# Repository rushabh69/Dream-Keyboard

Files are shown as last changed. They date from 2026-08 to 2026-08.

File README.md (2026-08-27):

# My KEEB Keyboard

A 65% mechanical keyboard I'm building for [Hack Club KEEB](https://keeb.hackclub.com/), with
a rotary encoder, hotswap switches, RGB, and an OLED.

## Specs

- 65% layout with an encoder cluster (67 keys, 5×15 matrix)
- Rotary encoder (volume / page scroll), hotswap switches
- RGB lighting (SK6812) and a 128×64 OLED
- Raspberry Pi Pico (RP2040)
- RMK firmware (Rust)
- PCB designed in KiCad
- 3D-printed case, designed in Onshape

## Build

The PCB is in [`pcb/`](pcb/) (KiCad), the case in [`case/`](case/) (Onshape), and the
firmware config in [`firmware/keyboard.toml`](firmware/keyboard.toml). I'm keeping the
build log in [`JOURNAL.md`](JOURNAL.md) as I go.

## Files

- [`pcb/`](pcb/) — PCB and schematic files (KiCad), plus exported Gerbers and drill files
- [`case/`](case/) — case and plate CAD, exported as STEP/STL (mm)
- [`firmware/`](firmware/) — RMK firmware config
- [`photos/`](photos/) — build photos
- [`bom.csv`](bom.csv) — parts list
- [`JOURNAL.md`](JOURNAL.md) — build log

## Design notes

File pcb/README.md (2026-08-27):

# PCB

KiCad project for the keyboard PCB. 65% layout with an encoder cluster, hotswap sockets,
RGB and an OLED. Raspberry Pi Pico as the controller, one 1N4148 diode per key.

Matrix: 5 rows × 15 cols. Pin mapping (matches `firmware/keyboard.toml`):

| Signal | Pico GPIO |
|---|---|
| ROW0–ROW4 | GP0–GP4 |
| COL0–COL14 | GP5–GP19 |
| Encoder A / B | GP20 / GP21 |
| RGB (WS2812 DIN) | GP22 |
| OLED SDA / SCL (I2C1) | GP26 / GP27 |

Parts / footprints to add (marbastlib for the keyboard parts):

- **Hotswap sockets** — Kailh MX hotswap footprint (marbastlib `SW_MX_1u` hotswap variant),
  not soldered switches.
- **Encoder** — EC11 rotary encoder footprint; A/B to GP20/GP21, encoder push wired into the
  matrix at (row0, col14).
- **RGB** — SK6812 MINI-E LEDs chained (DIN→DOUT), data from GP22, plus decoupling caps.
- **OLED** — 4-pin I2C header (GND/VCC/SCL/SDA) to GP27/GP26.

Switches on the 19.05 mm grid. Run DRC, then export Gerbers + drill files to `gerbers/`.

## Start from the layout (auto-place the matrix)

`layout.kle.json` is the full 65% layout with each key labelled by its `row,col` matrix
position. Instead of placing 67 keys by hand:

`dream-keyboard.net` is a pre-generated KiCad netlist for the whole matrix — all 67
switches + 67 diodes, wired to nets ROW0–ROW4 and COL0–COL14. It was generated from
`layout.kle.json` with `kle2netlist` (switch = `PCM_marbastlib-mx:SW_MX_1u`,
diode = `Diode_THT:D_DO-35_SOD27_P7.62mm_Horizontal`).

Bring the matrix into a PCB:

1. Install the **marbastlib** library so the switch footprint resolves.
2. New KiCad project in this folder → open the **PCB Editor**.
3. **File → Import → Netlist** → pick `dream-keyboard.net` → **Update PCB**. All 67
   switch+diode pairs load with the matrix already connected (you'll see the ratsnest).
4. Install the **kbplacer** plugin (Plugin and Content Manager) and run it with
   `layout.kle.json` to auto-arrange the switches on the 19.05 mm grid.
   - kbplacer: https://github.com/adamws/kbplacer
5. Hand-add the Pico, encoder, OLED header, and SK6812 chain, and wire them to the GPIO in
   the pin table above.
6. Draw the outline, route, DRC, export Gerbers.

The netlist covers only the key matrix — the Pico/encoder/OLED/RGB are added by hand.

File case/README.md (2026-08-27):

# Case

Case and plate designed in Onshape, 3D printed.

Rough dimensions: base 3–5 mm, walls ~12 mm, 14 mm switch cutouts on the 19.05 mm grid,
USB slot for the Pico's USB-C. Also needs a cutout/window for the OLED and clearance for
the encoder knob in the top-right. Exported to STL (mm) for printing and STEP for the repo.

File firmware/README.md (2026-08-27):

# Firmware

RMK (Rust) firmware for the Pico. Config is in [`keyboard.toml`](keyboard.toml).

Features wired in:
- **Rotary encoder** — volume on the base layer, page scroll on Fn.
- **OLED (SSD1306, 128×64, I2C1)** — configured in TOML.
- **Macro cluster** — M1/M2/M3 = copy / paste / cut.
- **Two layers** — base 65% and an Fn layer (F-keys + nav).
- **RGB (WS2812)** — the data line is on GP22, but addressable RGB isn't set up in
  `keyboard.toml`; RMK needs a small amount of Rust for it. Add it after the base build
  works: https://rmk.rs/docs/

## Build & flash

```bash
cargo install rmkit
rmkit init            # rp2040, keyboard.toml
# drop this keyboard.toml over the generated one
cargo build --release
```

Then hold BOOTSEL on the Pico, plug in USB, and copy the `.uf2` to the `RPI-RP2` drive.

The matrix, encoder, and I2C pins in `keyboard.toml` must match the KiCad schematic nets.
Default wiring is col2row (diode cathode → row); add `row2col = true` if it's reversed.

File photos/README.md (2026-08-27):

# Photos

Build and assembly photos, referenced from the journal and main README.

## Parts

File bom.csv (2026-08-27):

ref | component | description | quantity | value | source
SW1-SW67 | Switches | MX mechanical switches | 67 |  | grant
D1-D67 | Diode | 1N4148 (SOD-27 through-hole) | 67 | 1N4148
U1 | Controller | Raspberry Pi Pico | 1 | RP2040
ENC1 | Rotary encoder | Alps EC11 encoder + knob (with push) | 1 | EC11
D101-D105 | RGB | SK6812MINI-E addressable LED (5 zones) | 5 | SK6812
C101-C105 | Capacitor | 100nF decoupling (0805) | 5 | 100nF
J1 | Display | OLED header 1x04 (SSD1306 128x64 module) | 1 | SSD1306
R1-R2 | Resistor | I2C pull-up 4.7k (0805) | 2 | 4.7k
- | Keycaps | MX keycap set | 1 |  | grant
- | Cable | USB-C cable | 1 |  | grant
- | Stabilizers | MX plate/PCB stabilizers | 5
- | Case | 3D-printed case | 1
- | Plate | Switch plate | 1

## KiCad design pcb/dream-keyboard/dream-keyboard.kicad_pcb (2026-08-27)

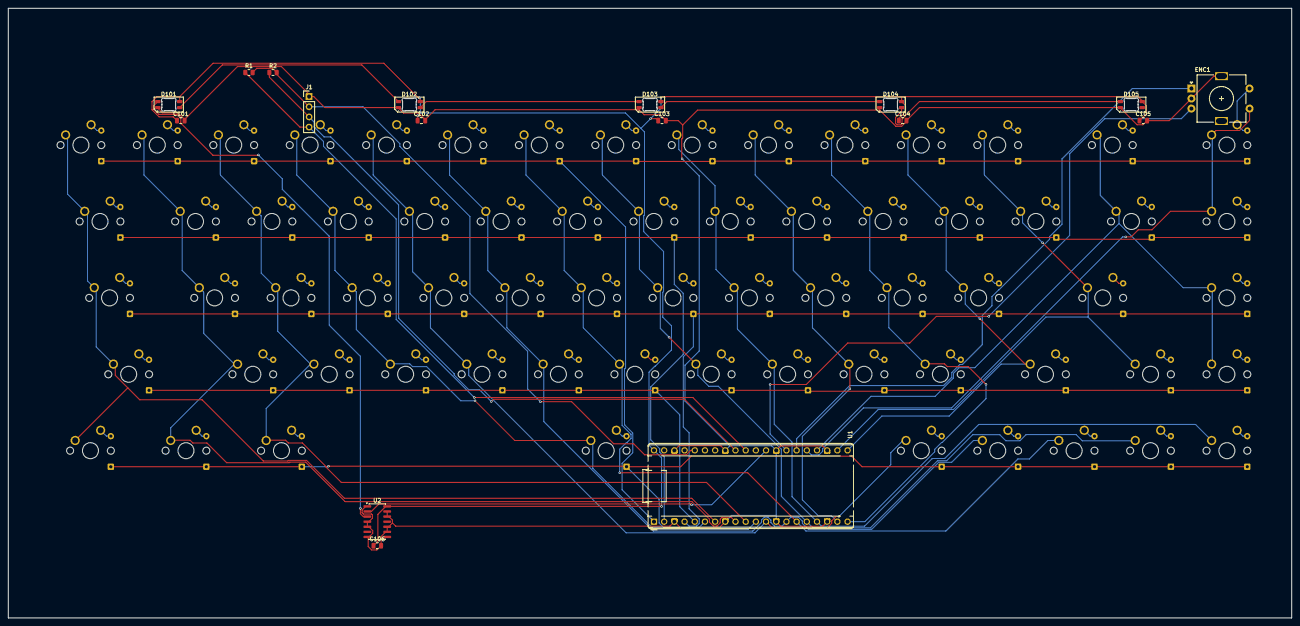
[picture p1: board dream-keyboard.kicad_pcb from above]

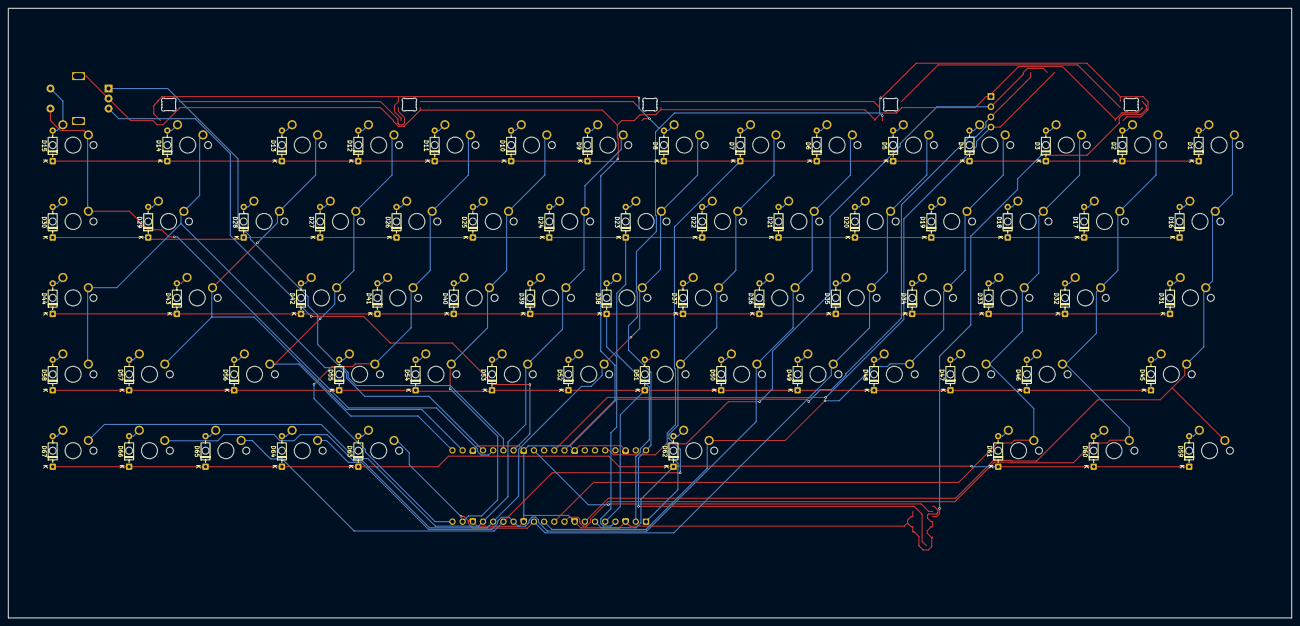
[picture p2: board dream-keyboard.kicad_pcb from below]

Board: 2 copper layers, 320.0 x 152.0 mm, 151 parts (67 on the bottom side), 100 nets.

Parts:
C101, C102, C103, C104, C105, C106: C_0805_2012Metric
D1, D2, D3, D4, D5, D6, D7, D8, D9, D10, D11, D12, D13, D14, D15, D16, D17, D18, D19, D20, D21, D22, D23, D24, D25, D26, D27, D28, D29, D30, D31, D32, D33, D34, D35, D36, D37, D38, D39, D40, D41, D42, D43, D44, D45, D46, D47, D48, D49, D50, D51, D52, D53, D54, D55, D56, D57, D58, D59, D60, D61, D62, D63, D64, D65, D66, D67: D; D_DO-35_SOD27_P7.62mm_Horizontal
D101, D102, D103, D104, D105: LED_SK6812MINI-E_3.2x2.8mm_P1.5mm_ReverseMount
ENC1: RotaryEncoder_Alps_EC11E-Switch_Vertical_H20mm
J1: PinHeader_1x04_P2.54mm_Vertical
R1, R2: R_0805_2012Metric
SW1, SW2, SW3, SW4, SW5, SW6, SW7, SW8, SW9, SW10, SW11, SW12, SW13, SW14, SW15, SW16, SW17, SW18, SW19, SW20, SW21, SW22, SW23, SW24, SW25, SW26, SW27, SW28, SW29, SW30, SW31, SW32, SW33, SW34, SW35, SW36, SW37, SW38, SW39, SW40, SW41, SW42, SW43, SW44, SW45, SW46, SW47, SW48, SW49, SW50, SW51, SW52, SW53, SW54, SW55, SW56, SW57, SW58, SW59, SW60, SW61, SW62, SW63, SW64, SW65, SW66, SW67: SW_Push; SW_MX_1u
U1: RaspberryPi_Pico_Common_THT
U2: SOIC-14_3.9x8.7mm_P1.27mm

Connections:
+3V3: J1.2, R1.2, R2.2, U1.36
+5V: C101.1, C102.1, C103.1, C104.1, C105.1, C106.1, D101.3, D102.3, D103.3, D104.3, D105.3, U1.40, U2.14
COL0: SW1.1, SW16.1, SW31.1, SW45.1, SW59.1, U1.7
COL1: SW2.1, SW17.1, SW32.1, SW46.1, SW60.1, U1.9
COL2: SW3.1, SW18.1, SW33.1, SW47.1, SW61.1, U1.10
COL3: SW4.1, SW19.1, SW34.1, SW48.1, SW62.1, U1.11
COL4: SW5.1, SW20.1, SW35.1, SW49.1, SW63.1, U1.12
COL5: SW6.1, SW21.1, SW36.1, SW50.1, SW64.1, U1.14
COL6: SW7.1, SW22.1, SW37.1, SW51.1, SW65.1, U1.15
COL7: SW8.1, SW23.1, SW38.1, SW52.1, SW66.1, U1.16
COL8: SW9.1, SW24.1, SW39.1, SW53.1, SW67.1, U1.17
COL9: SW10.1, SW25.1, SW40.1, SW54.1, U1.19
COL10: SW11.1, SW26.1, SW41.1, SW55.1, U1.20
COL11: SW12.1, SW27.1, SW42.1, SW56.1, U1.21
COL12: SW13.1, SW28.1, SW43.1, SW57.1, U1.22
COL13: SW14.1, SW29.1, SW44.1, SW58.1, U1.24
COL14: ENC1.S1, SW15.1, SW30.1, U1.25
ENC_A: ENC1.A, U1.26
ENC_B: ENC1.B, U1.27
GND: C101.2, C102.2, C103.2, C104.2, C105.2, C106.2, D101.1, D102.1, D103.1, D104.1, D105.1, ENC1.C, ENC1.MP, J1.1, U1.3, U1.8, U1.13, U1.18, U1.23, U1.28, U1.33, U1.38, U2.1, U2.4, U2.5, U2.7, U2.9, U2.10, U2.12, U2.13
I2C_SCL: J1.3, R2.1, U1.32
I2C_SDA: J1.4, R1.1, U1.31
LED_D0: D101.2, U2.3
LED_D1: D101.4, D102.2
LED_D2: D102.4, D103.2
LED_D3: D103.4, D104.2
LED_D4: D104.4, D105.2
unnamed: D1.2, SW1.2
unnamed: D2.2, SW2.2
unnamed: D3.2, SW3.2
unnamed: D4.2, SW4.2
unnamed: D5.2, SW5.2
unnamed: D6.2, SW6.2
unnamed: D7.2, SW7.2
unnamed: D8.2, SW8.2
unnamed: D9.2, SW9.2
unnamed: D10.2, SW10.2
unnamed: D11.2, SW11.2
unnamed: D12.2, SW12.2
unnamed: D13.2, SW13.2
unnamed: D14.2, SW14.2
unnamed: D15.2, ENC1.S2, SW15.2
unnamed: D16.2, SW16.2
unnamed: D17.2, SW17.2
unnamed: D18.2, SW18.2
unnamed: D19.2, SW19.2
unnamed: D20.2, SW20.2
unnamed: D21.2, SW21.2
unnamed: D22.2, SW22.2
unnamed: D23.2, SW23.2
unnamed: D24.2, SW24.2
unnamed: D25.2, SW25.2
unnamed: D26.2, SW26.2
unnamed: D27.2, SW27.2
unnamed: D28.2, SW28.2
unnamed: D29.2, SW29.2
unnamed: D30.2, SW30.2
unnamed: D31.2, SW31.2
unnamed: D32.2, SW32.2
unnamed: D33.2, SW33.2
unnamed: D34.2, SW34.2
unnamed: D35.2, SW35.2
unnamed: D36.2, SW36.2
unnamed: D37.2, SW37.2
unnamed: D38.2, SW38.2
unnamed: D39.2, SW39.2
unnamed: D40.2, SW40.2
unnamed: D41.2, SW41.2
unnamed: D42.2, SW42.2
unnamed: D43.2, SW43.2
unnamed: D44.2, SW44.2
unnamed: D45.2, SW45.2
unnamed: D46.2, SW46.2
unnamed: D47.2, SW47.2
unnamed: D48.2, SW48.2
unnamed: D49.2, SW49.2
unnamed: D50.2, SW50.2
unnamed: D51.2, SW51.2
unnamed: D52.2, SW52.2
unnamed: D53.2, SW53.2
unnamed: D54.2, SW54.2
unnamed: D55.2, SW55.2
unnamed: D56.2, SW56.2
unnamed: D57.2, SW57.2
unnamed: D58.2, SW58.2
unnamed: D59.2, SW59.2
unnamed: D60.2, SW60.2
unnamed: D61.2, SW61.2
unnamed: D62.2, SW62.2
unnamed: D63.2, SW63.2
unnamed: D64.2, SW64.2
unnamed: D65.2, SW65.2
unnamed: D66.2, SW66.2
unnamed: D67.2, SW67.2
RGB_IN: U1.29, U2.2
ROW0: D1.1, D2.1, D3.1, D4.1, D5.1, D6.1, D7.1, D8.1, D9.1, D10.1, D11.1, D12.1, D13.1, D14.1, D15.1, U1.1
ROW1: D16.1, D17.1, D18.1, D19.1, D20.1, D21.1, D22.1, D23.1, D24.1, D25.1, D26.1, D27.1, D28.1, D29.1, D30.1, U1.2
ROW2: D31.1, D32.1, D33.1, D34.1, D35.1, D36.1, D37.1, D38.1, D39.1, D40.1, D41.1, D42.1, D43.1, D44.1, U1.4
ROW3: D45.1, D46.1, D47.1, D48.1, D49.1, D50.1, D51.1, D52.1, D53.1, D54.1, D55.1, D56.1, D57.1, D58.1, U1.5
ROW4: D59.1, D60.1, D61.1, D62.1, D63.1, D64.1, D65.1, D66.1, D67.1, U1.6

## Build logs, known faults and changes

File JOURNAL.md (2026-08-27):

# Build Journal

Logging what I do as I go, with hours and photos (KEEB checks these). Newest first.

Total so far: ~30h

---

### 2026-08-27 — Design, repo, layout, and full PCB
**Hours: ~30h (cumulative, approximate)**

What I did:
- Chose the build: 65% layout with an encoder cluster, hotswap switches, RGB, and an OLED.
  Controller: Raspberry Pi Pico (RP2040). Firmware: RMK.
- Set up the GitHub repo and the project structure (pcb / case / firmware / photos).
- Wrote the firmware config (`firmware/keyboard.toml`): 5×15 matrix, base + Fn layers,
  rotary encoder, and OLED.
- Designed the physical layout in Keyboard Layout Editor; fixed the arrow cluster so the
  up arrow sits above the down arrow.
- Generated the switch-matrix netlist from the layout and imported it into KiCad.
- Placed the 67 switches + diodes and routed the matrix (kbplacer + autorouter).
- Wired the Pico to the matrix (ROW0–4 → GP0–4, COL0–14 → GP5–19).
- Added and wired the extras: rotary encoder (GP20/21), OLED header + I2C pull-ups
  (GP26/27), a 5-zone SK6812 RGB chain (GP22) with a 74AHCT125 level shifter, and the
  +5V / +3V3 / GND power network.
- Verified connectivity net-by-net, ran DRC (0 unconnected), and exported Gerbers.

Board size ended up 320×152mm. Next: case design in Onshape (OLED window, encoder-knob
hole, RGB), then flash the firmware and order the PCB.

<!-- Add photos of the KiCad board / first PCB when available -->

---

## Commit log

2026-08-27 Initial commit: Dream Keyboard project
    [bom.csv]
2026-08-27 Add routed PCB (encoder, OLED, RGB + level shifter), Gerbers, updated docs
    [bom.csv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]
